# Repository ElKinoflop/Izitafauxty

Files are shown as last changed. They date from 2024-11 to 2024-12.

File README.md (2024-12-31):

# Izitafauxty Keyboard

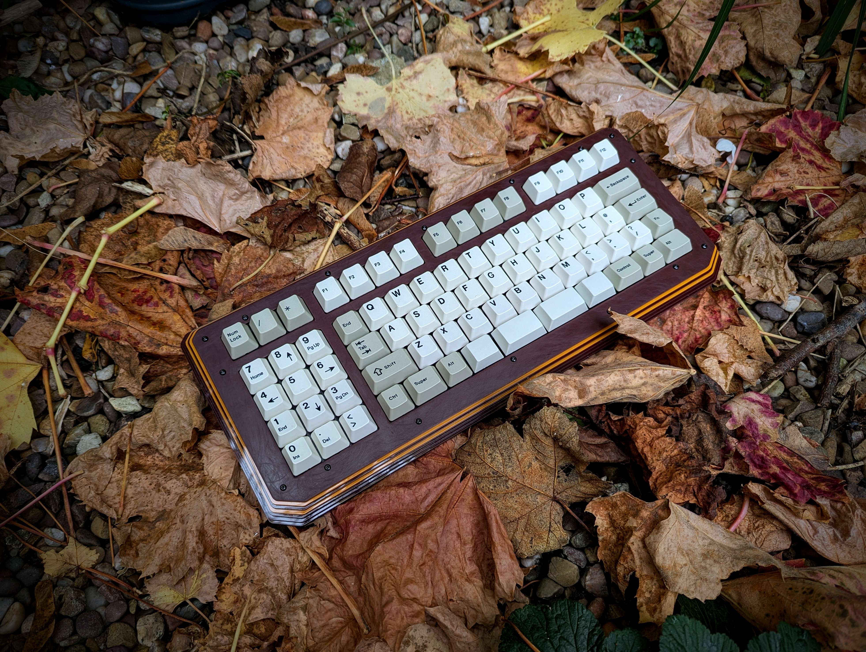
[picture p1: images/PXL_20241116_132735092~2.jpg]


Stacked acrylic keyboard case designed for handwiring with a <a href="https://www.waveshare.com/wiki/RP2040-Tiny" target="_blank">Waveshare RP2040-Tiny</a>. Main cluster is minivan sized (12.75u) with an added F-Row and numpad (standard or southpaw).

Feel free to do whatever you want with the files. If you have any questions just ask (Discord username elkinoflop) and if you make one then share a photo with me!

<h1>Layout</h1>
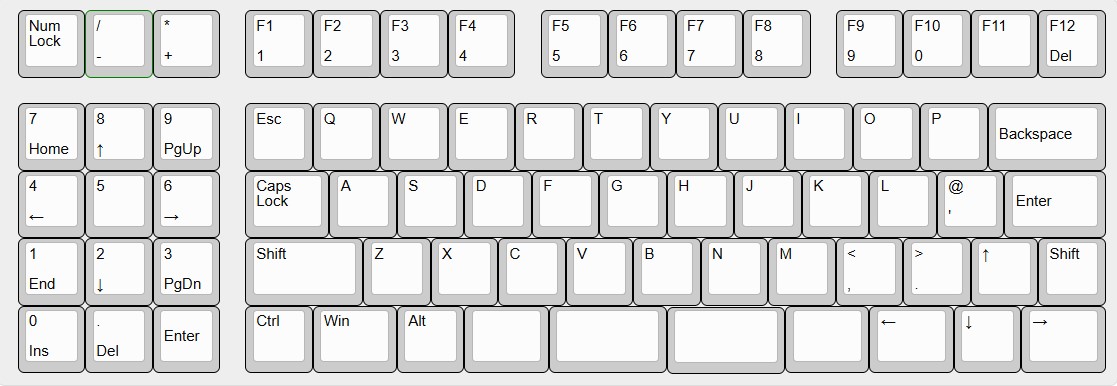
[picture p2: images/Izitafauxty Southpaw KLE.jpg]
Izitafauxty KLE Image


<h1>KLE Raw Data</h1>
Standard:
[{y:1},"F1\n1","F2\n2","F3\n3","F4\n4",{x:0.375},"F5\n5","F6\n6","F7\n7","F8\n8",{x:0.375},"F9\n9","F10\n0","F11","F12\nDel",{x:0.375},"Num Lock","/\n-","*\n+"],
[{y:0.375},"Esc","Q","W","E","R","T","Y","U","I","O","P",{a:6,w:1.75},"Backspace",{x:0.375,a:4},"7\nHome","8\n↑","9\nPgUp"],
[{w:1.25},"Caps Lock","A","S","D","F","G","H","J","K","L","@\n'",{a:6,w:1.5},"Enter",{x:0.375,a:4},"4\n←","5","6\n→"],
[{w:1.75},"Shift","Z","X","C","V","B","N","M","<\n,",">\n.","↑",{x:1.375},"1\nEnd","2\n↓","3\nPgDn"],
[{y:-0.995,x:11.75},"Shift"],
[{y:-0.005},"Ctrl",{w:1.25},"Win","Alt",{a:7,w:1.25},"",{x:4.75,a:4,w:1.25},"←",{x:2.625},"0\nIns",".\nDel",{a:6},"Enter"],
[{y:-0.995,x:4.5,a:7,w:1.75},"",{x:1.75,w:1.25},"",{x:1.25,a:4},"↓",{w:1.25},"→"],
[{y:-0.99,x:6.25,a:7,w:1.75},""]

  Southpaw:
[{x:0.13},"Num Lock","/\n-","*\n+",{x:0.37},"F1\n1","F2\n2","F3\n3","F4\n4",{x:0.38},"F5\n5",{x:0},"F6\n6","F7\n7","F8\n8",{x:0.37},"F9\n9","F10\n0","F11","F12\nDel"],
[{y:0.38,x:0.13},"7\nHome","8\n↑","9\nPgUp",{x:0.37},"Esc","Q","W","E","R","T","Y","U","I","O","P",{a:6,w:1.75},"Backspace"],
[{x:0.13,a:4},"4\n←","5","6\n→",{x:0.37,w:1.25},"Caps Lock","A","S","D","F","G","H","J","K","L","@\n'",{a:6,w:1.5},"Enter"],
[{x:0.13,a:4},"1\nEnd","2\n↓","3\nPgDn",{x:0.37,w:1.75},"Shift","Z","X","C","V","B","N","M","<\n,",">\n.","↑","Shift"],
[{x:0.13},"0\nIns",".\nDel",{a:6},"Enter",{x:0.37,a:4},"Ctrl",{w:1.25},"Win","Alt",{a:7,w:1.25},"",{w:1.75},"",{x:1.75,w:1.25},"",{a:4,w:1.25},"←","↓",{w:1.25},"→"],
[{y:-0.99,x:9.75,a:7,w:1.75},""]

<h1>Case</h1>
<ul>
  <li>Designed to be cut from 3mm acrylic</li>
</ul>

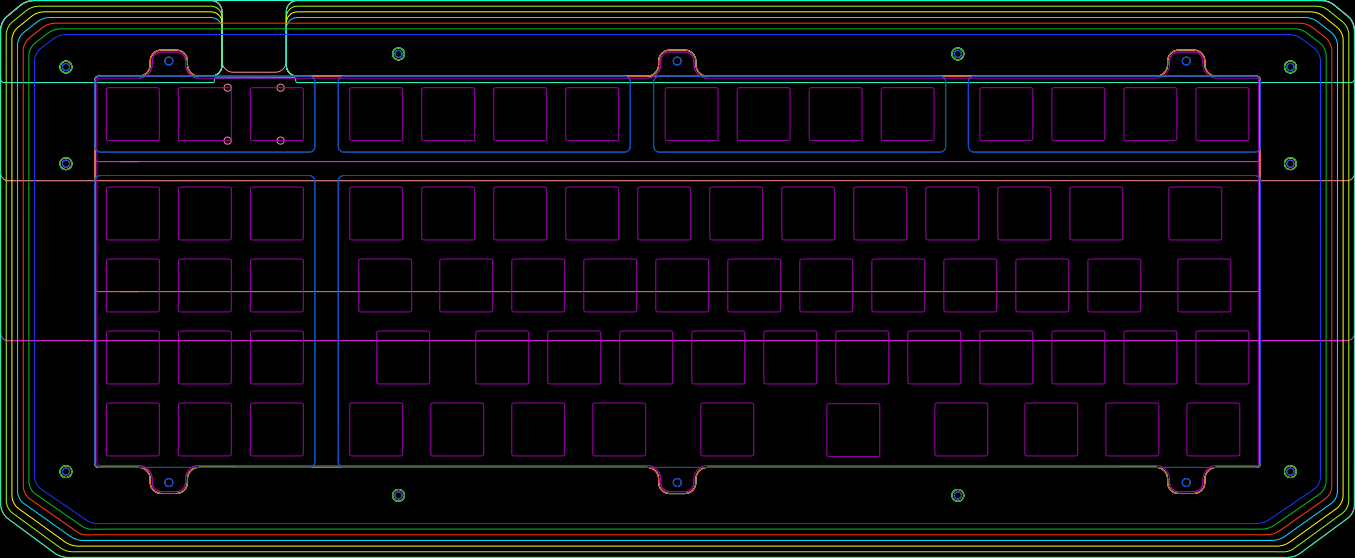
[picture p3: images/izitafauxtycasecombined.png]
Izitafauxty Case Layers


<h1>Bill of Materials</h1>
<ul>
  <li>One of each DXF file (except for the plate) cut from 3mm acrylic. You only need 1x layer 1 and 1x layer 2 piece cut depending on whether you want standard or southpaw</li>
  <li>Plate DXF file cut from 1.5mm/1.6mm material of your choice. I've only tested this with carbon, plastic might be too flexy.</li>
  <li><a href="https://www.waveshare.com/wiki/RP2040-Tiny" target="_blank">Waveshare RP2040-Tiny</a></li>
  <li>M2 Standoffs with a outside diameter of 3mm. Various lengths. <a href="https://amzn.eu/d/8H1HG6Y" target="_blank">Amazon Standoffs</a></li></li>
  <li>M2 Hex socket button head bolts. Various lengths. <a href="https://www.aliexpress.com/item/32969042589.html" target="_blank">AliExpress bolts</a></li>
  <li>M2 Washers. To space the plate downwards to tune the keycap height (normally 2mm worth under each plate mounting bolt). Also for under the bolt heads that hold the daughterboard in.<a href="https://www.aliexpress.com/item/1005003697132040.html" target="_blank">AliExpress M2 0.5mm thickness plastic washers</a></li>
<li>M2 nuts to hold the daughterboard. Included with the standoffs linked above</li>
  <li>Wire! Solid core 22 AWG suggested</li>
  <li>73x MX Switches</li>
  <li>73x 1N4148 Diodes</li>
  <li>Adhesive feet</li>
</ul>

<h1>Firmware</h1>
I used <a href="https://github.com/JanLunge/pog" target="_blank">POG</a>  to create <a href="https://github.com/KMKfw/kmk_firmware" target="_blank">KMK</a> firmware. POG makes creating firmware super simple but I might learn how to create QMK/VIAL firmware at some point!
I have included my firmware files (generated by POG). 

If you have wired up the matrix and connected it to the same controller pins as I have then you should be able to use my firmware. Install <a href="https://circuitpython.org/board/waveshare_rp2040_tiny/" target="_blank">Circuit Python</a> onto the controller first and then copy all the files from <a href="https://github.com/ElKinoflop/Izitafauxty/tree/main/KMK%20Firmware" target="_blank">'KMK Firmware'</a> onto the drive

<h1>Handwired Matrix</h1>
This is how I handwired the Matrix.
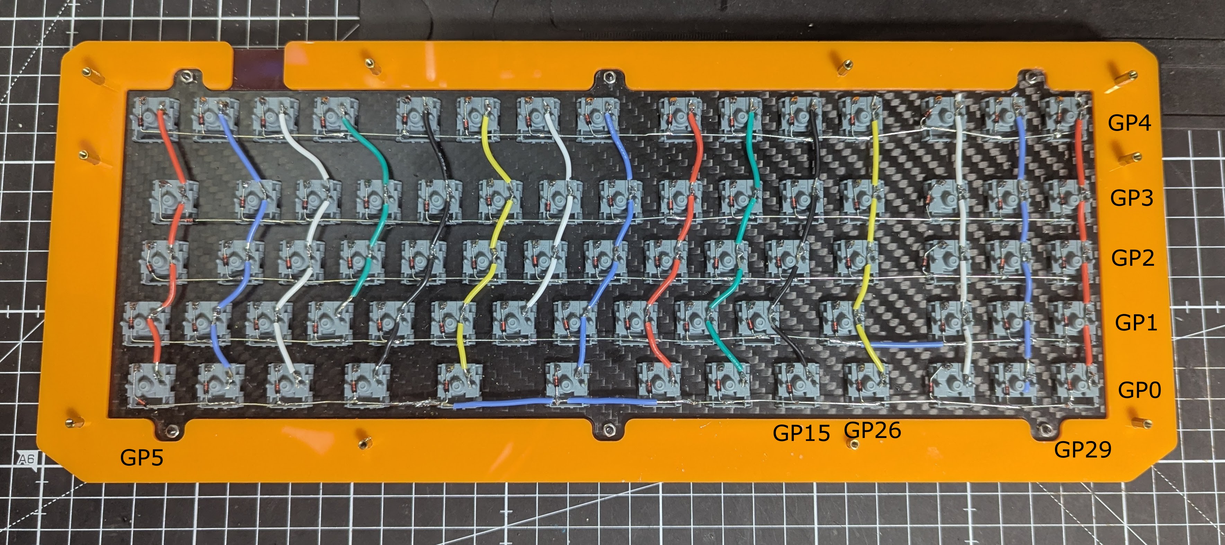
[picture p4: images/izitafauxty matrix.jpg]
Izitafauxty Handiwired Matrix


<h1>Case Assembly</h1>
If you find some of the standoffs tight to push through don't force them. Use a small round file if you need to slightly widen any holes. The small round file from Draper 'Soft Grip Needle File Set, 140mm (6 Piece) (83982)' is the perfect size.

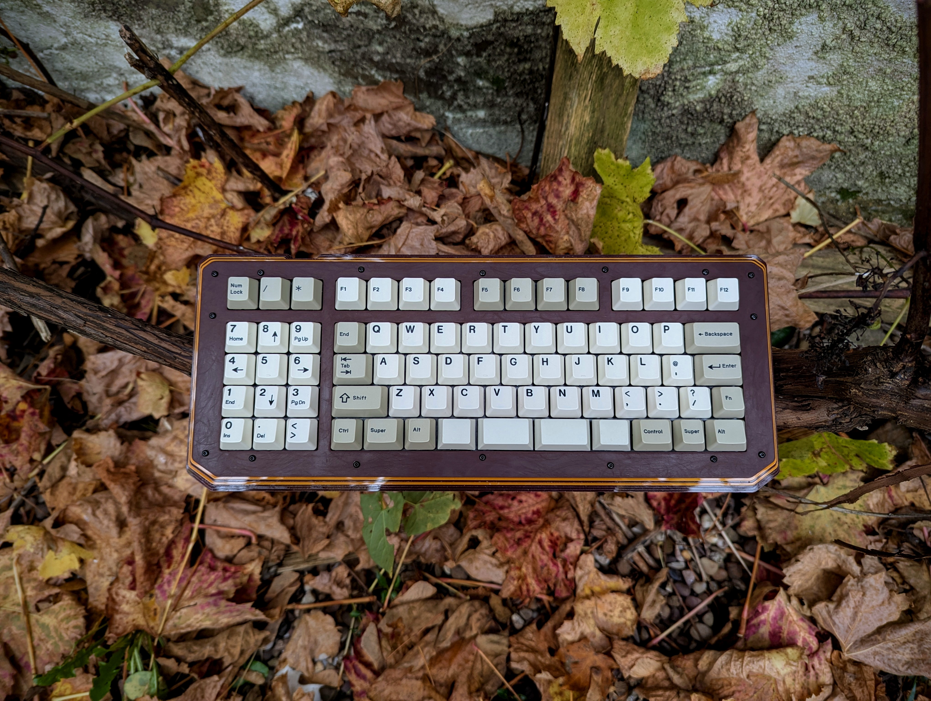
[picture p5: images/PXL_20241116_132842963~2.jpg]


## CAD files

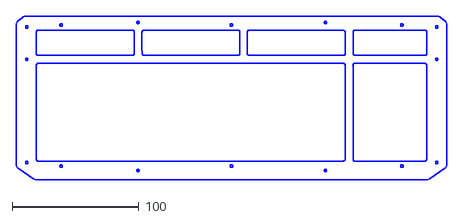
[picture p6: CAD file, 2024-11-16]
dxf/1 - Top.dxf
340.2 x 129.4

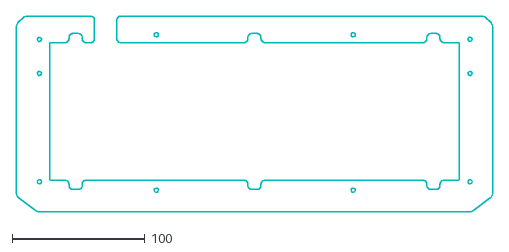
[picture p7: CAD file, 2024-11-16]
dxf/7 - Mid Extension.dxf
358.2 x 147.4

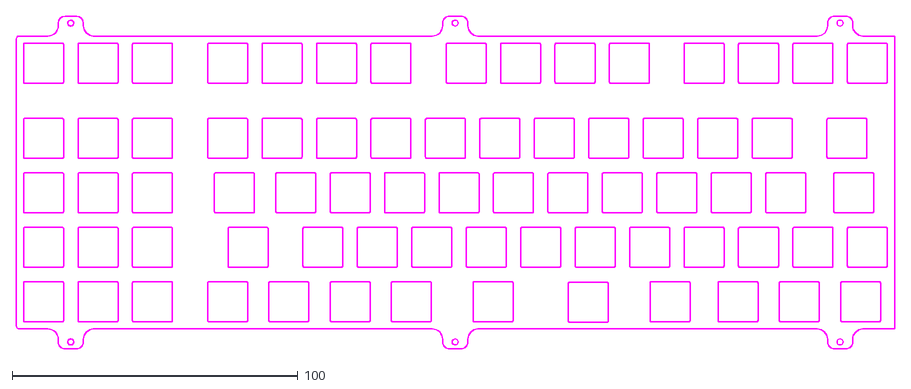
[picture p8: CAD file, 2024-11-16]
dxf/Izitafauxty SP Plate.dxf
307.3 x 116.3

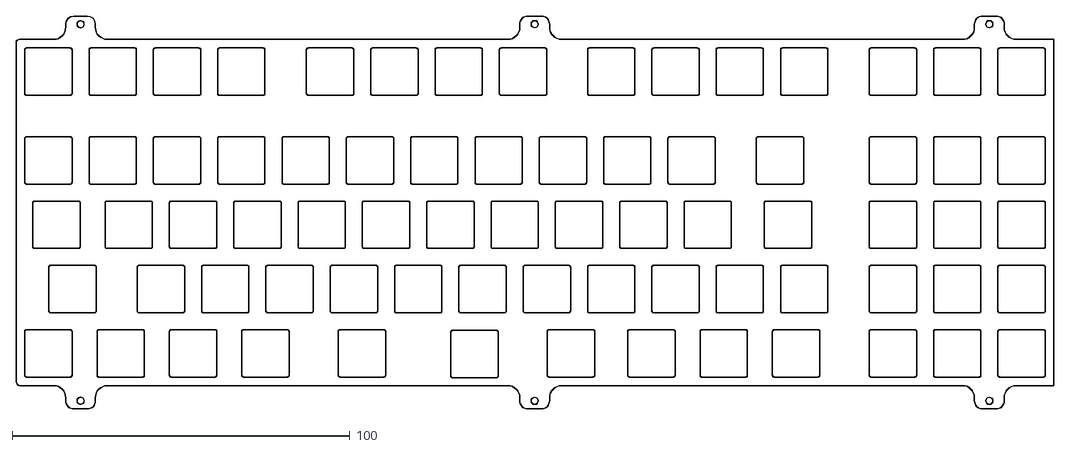
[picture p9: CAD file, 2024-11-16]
dxf/Izitafauxty Plate.dxf
307.3 x 116.3

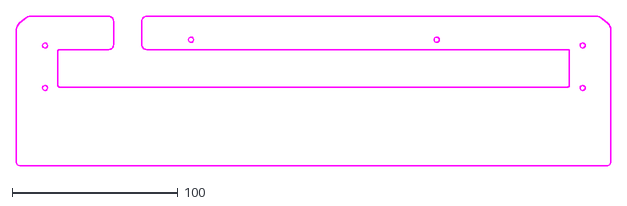
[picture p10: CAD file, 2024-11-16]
dxf/9 - Big Foot.dxf
358.2 x 90.0

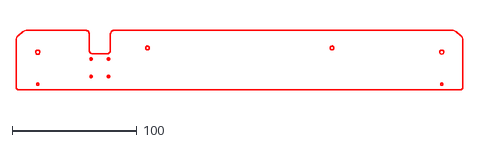
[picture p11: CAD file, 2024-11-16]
dxf/10 - Mid Foot.dxf
358.2 x 47.7

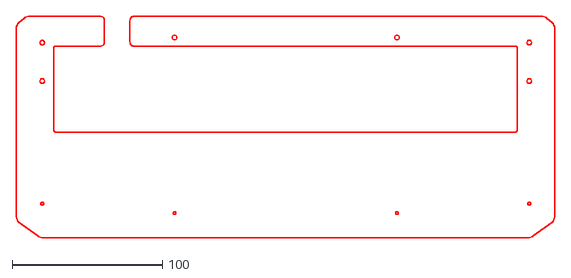
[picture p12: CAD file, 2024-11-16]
dxf/8 - Base.dxf
358.2 x 147.4

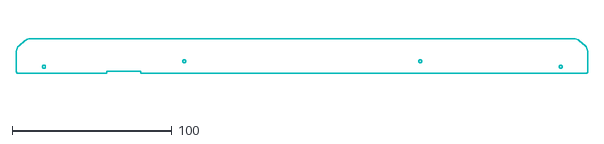
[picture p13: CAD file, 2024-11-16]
dxf/11 - Small Foot B.dxf
358.2 x 29.9

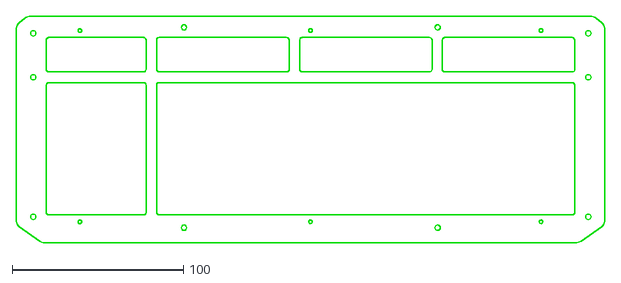
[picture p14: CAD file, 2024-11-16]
dxf/2 - Soutpaw Accent.dxf
343.2 x 132.4

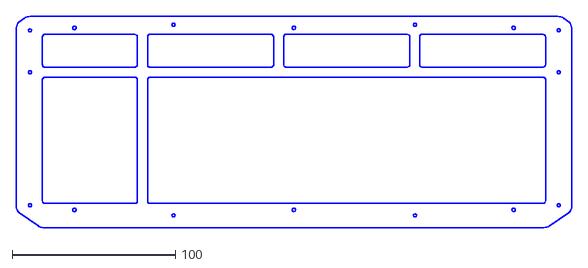
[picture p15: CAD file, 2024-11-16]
dxf/1 - Southpaw Top.dxf
340.2 x 129.4

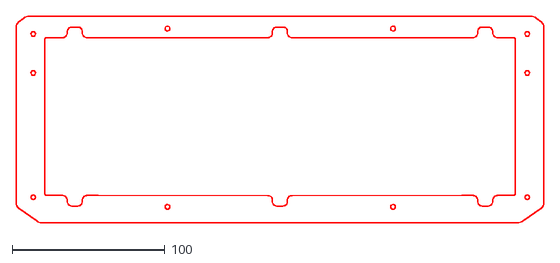
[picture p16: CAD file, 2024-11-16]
dxf/3 - Plate Layer.dxf
346.2 x 135.4

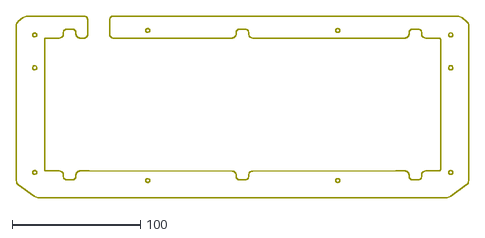
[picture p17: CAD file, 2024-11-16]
dxf/5 - Mid Middle.dxf
352.2 x 141.4

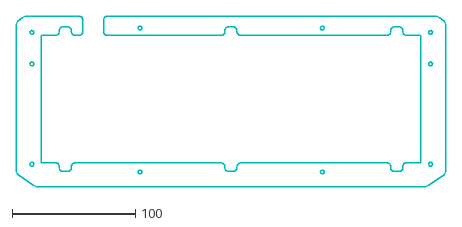
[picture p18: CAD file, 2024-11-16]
dxf/4 - Mid Top.dxf
349.2 x 138.4

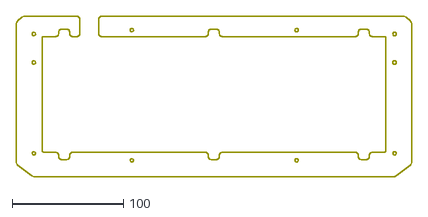
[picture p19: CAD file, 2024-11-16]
dxf/6 - Mid Lower.dxf
355.2 x 144.4

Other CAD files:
dxf/2 - Accent.dxf

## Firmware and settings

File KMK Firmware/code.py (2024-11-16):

# Main Keyboard Configuration - v1.0.0
import board
import pog
# check if we just want to run the coord_mappping Assistant
if pog.coordMappingAssistant:
    from coordmaphelper import CoordMapKeyboard
    if __name__ == '__main__':
        CoordMapKeyboard().go()
    print("Exiting Coord Mapping Assistant Because of an error")
else:
    from kb import POGKeyboard
    # set the required features for you keyboard and keymap
    # add custom ones in the kb.py

    keyboard = POGKeyboard(features=pog.kbFeatures)

    # manage settings for our modules and extensions here
    keyboard.tapdance.tap_time = 180

    # Keymap
    import keymap
    keyboard.keymap = keymap.keymap

    # Encoder Keymap if available
    if pog.hasEncoders:
        keyboard.encoder_handler.map = keymap.encoderKeymap

    # Execute the keyboard loop
    if __name__ == '__main__':
        keyboard.go()
